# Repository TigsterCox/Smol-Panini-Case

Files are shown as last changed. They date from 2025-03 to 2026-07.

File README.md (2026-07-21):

# Smol-Panini-Case
The Smol-Panini-Case is a SlimeVR Smols Case designed to utilise integrated Filament hinge.

<p align="center">
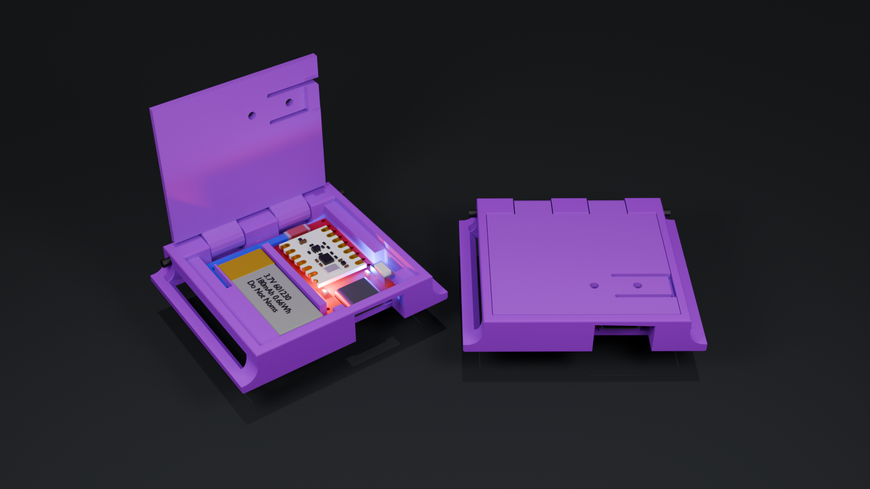
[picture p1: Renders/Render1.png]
	
</p>

# REVISION 2.1!
Revision 2.1 brings a slightly larger design in favor for strength and a better lid mechanism
 - Now locks into 90* increments
 - Lid sits flush! (no more getting it snagged!)
 - Matching insides for easy switch!

These cases have some intentionally tight tollerances on the hinges so that they are sufficiently stiff to assist with keeping the lid closed during use.
You can use a 2mm alankey or drill bit to make sure the gap is sufficient.
This case is intended to be used with 30mm straps which you can find [here](https://www.aliexpress.com/item/1005006112175102.html)

Things you will need:

 - Stacked Slime with 601230 180mah battery and button of choice (i used 3X6X2.5 button)
 - Case.stl
 - Lid.stl
 - 40-42mm of filament (per case)
 - Allen key (optional)
 - Something hot (solding iron set to the temp you print at is perfect)
 - Some wire

I would reccomend printing these out of PLA+, PETG or better @ 0.1mm layer height (0.2 is fine but doesnt look as nice).

CHECK YOUR ORIENTATIONS BEFORE PRINTING

After printing out the cases & lids you need: 
simply put the lid and case together.
push your peice of filament though leaving 1-2mm on each end, cut off the extra. (use a small allen key to help line it up if you are struggling)
Next, Using your "something hot" melt and flatten the ends of the extra filament, fusing it to the case
now give it a couple flippy flops opening and closing it.
This will just help loosen it up abit, dont worry about it getting loose too much, if you're opening it often, you're doing something wrong.

If you need some help, feel free to ping me in the #Smol-Slime Channel! @tigsteruk

Thanks go out to: 
 - Emil (Ketzal) for the name idea
 - Meia (KOUNOLAB's #1 employee) for the IMU's
 - Lexie (aka scwanf) for all of the hardwork developing smols and tollerating my harrasment
 - Shine Bright for creating the smol docs and allowing me to RTFM my way through some of this project
 - Lyall (Stacked Slime) for creating this format and providing firmware versions for use
 - The rest of the #Smol-Slime channel for all of the help with understanding how it all works

Hyperion Approved! <3

> Strap notes for your consideration; I'm a rarther heavy set 5'6 dude, I use these lengths from the strap link above:
> - Chest, Waist, Hips: 100CM 3x
> - Thighs: 60cm 2x
> - Ankles and forearms: 30cm 4x
> - Upper Arms: 40cm 2x

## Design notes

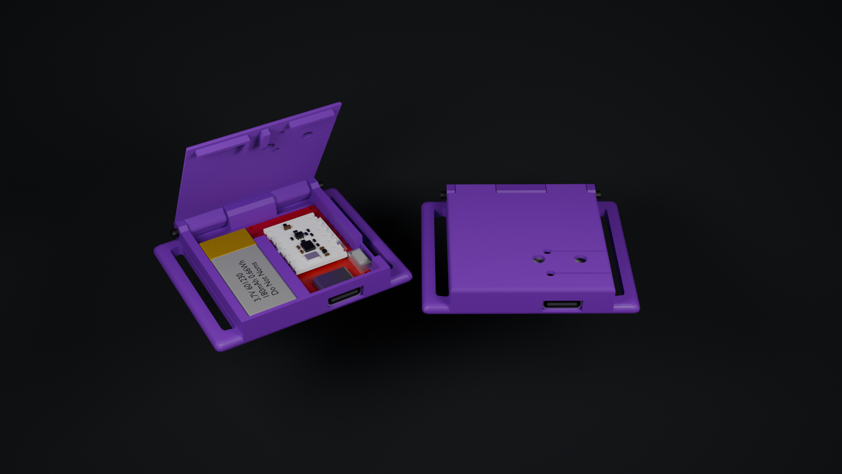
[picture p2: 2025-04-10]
Renders/RenderV1out.png

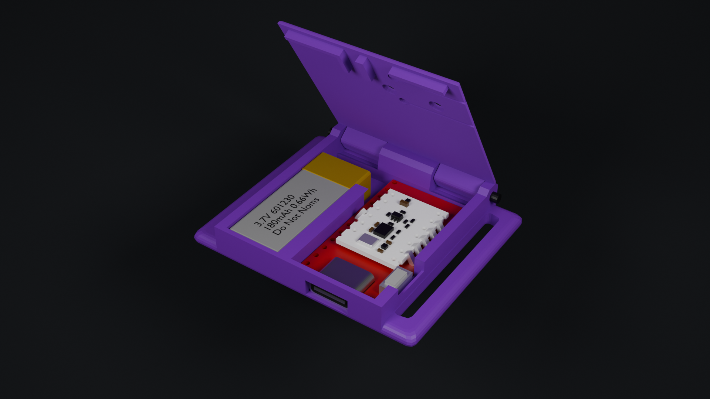
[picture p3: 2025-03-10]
Renders/RenderV1 original.png

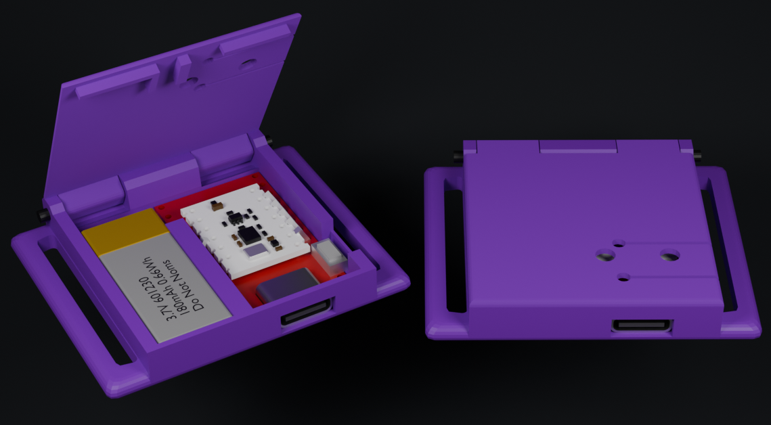
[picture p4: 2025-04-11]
Renders/Render V1crop.png

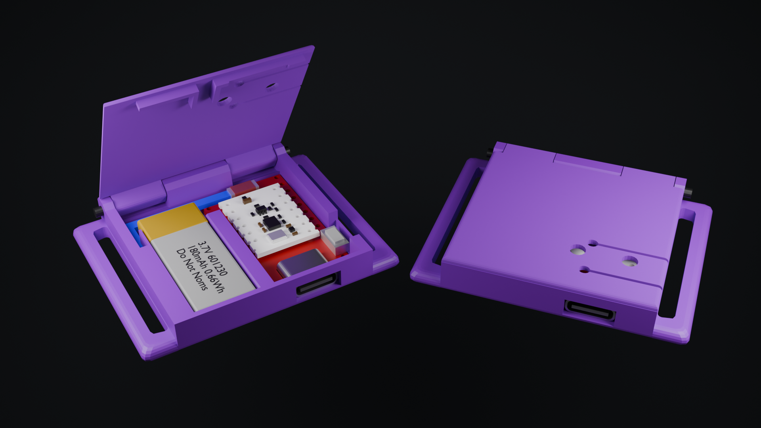
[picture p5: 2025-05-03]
Renders/Render V1.png

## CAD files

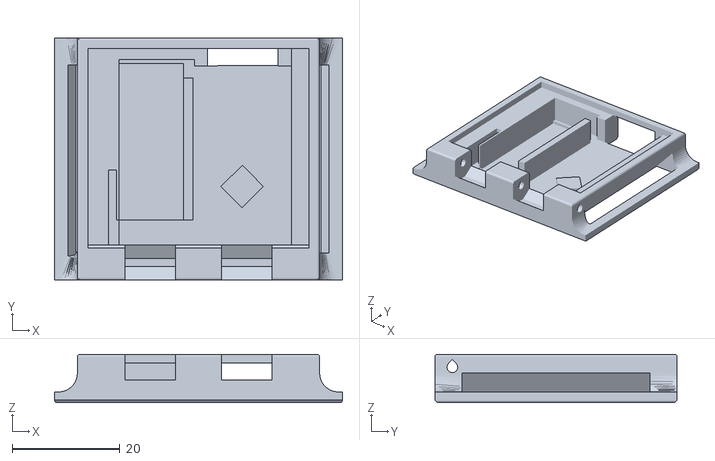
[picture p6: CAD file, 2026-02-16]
CAD/Smol Panini Case V2.stl
53.5 x 45.0 x 9.00

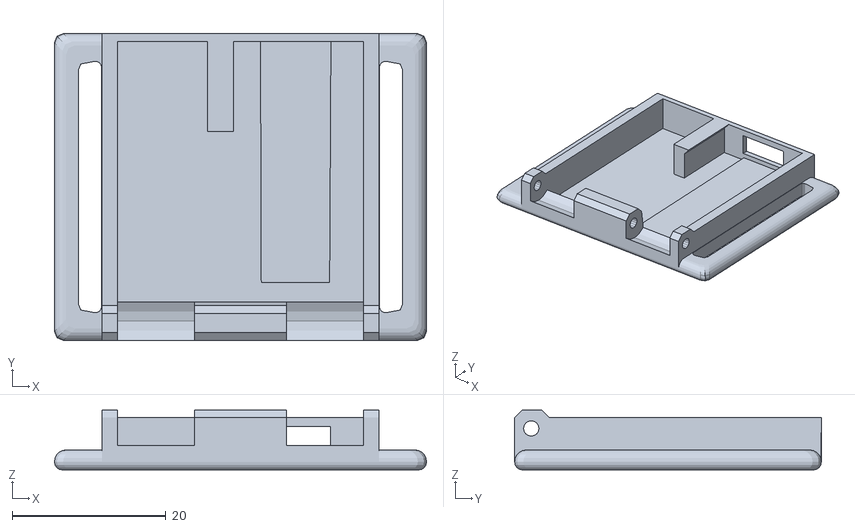
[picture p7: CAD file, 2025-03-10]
STLs/Beaver Track Case/Case.stl
48.4 x 39.9 x 7.79

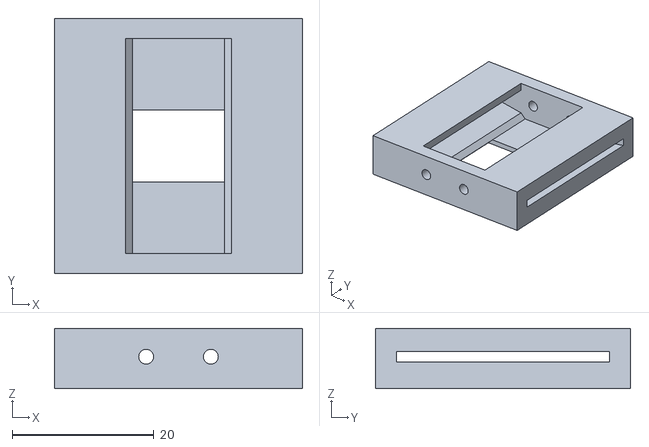
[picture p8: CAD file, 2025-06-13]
STLs/Smol Panini Case/30mm clips/Clasp.stl
35.0 x 36.0 x 8.50

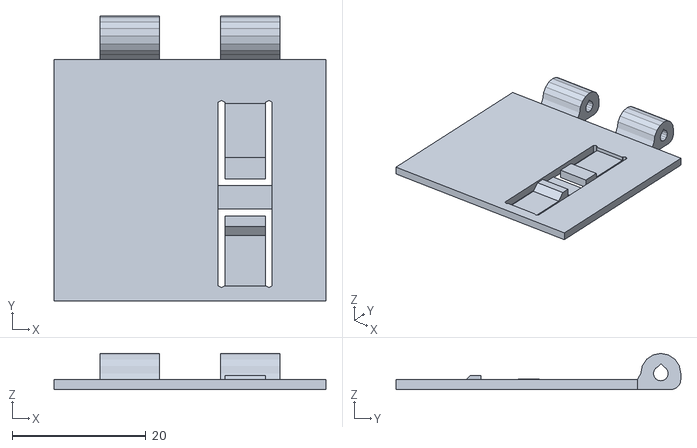
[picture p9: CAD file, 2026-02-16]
STLs/Smol Panini Case/Alternative Files/Experimental Chrysalis Lid.stl
40.7 x 42.6 x 5.41

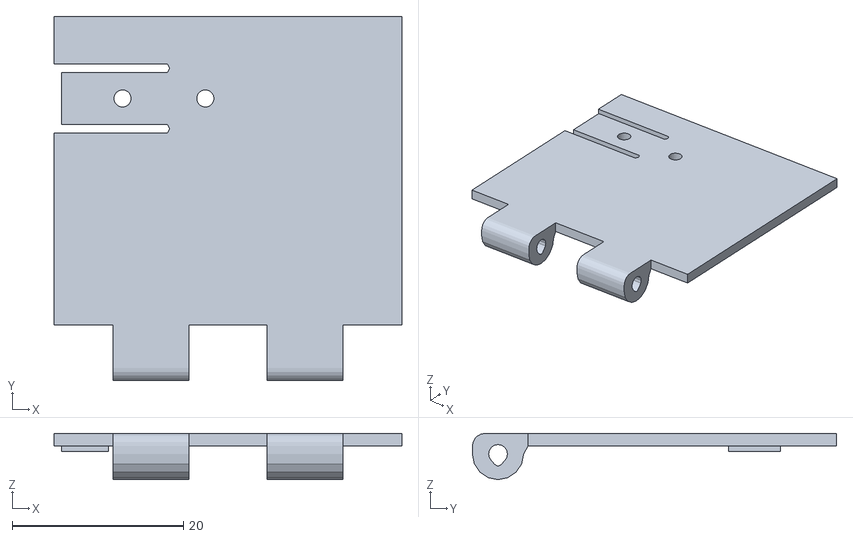
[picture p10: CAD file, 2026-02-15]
STLs/Smol Panini Case/Smol Panini Lid V3.2.stl
40.7 x 42.6 x 5.41

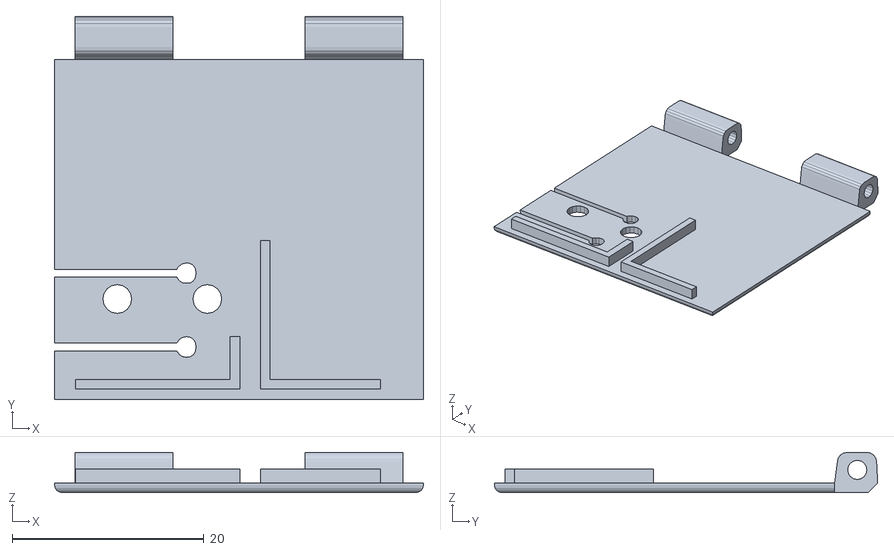
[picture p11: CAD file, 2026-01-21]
CAD/Smol Panini Lid V2.stl
38.5 x 40.0 x 4.20

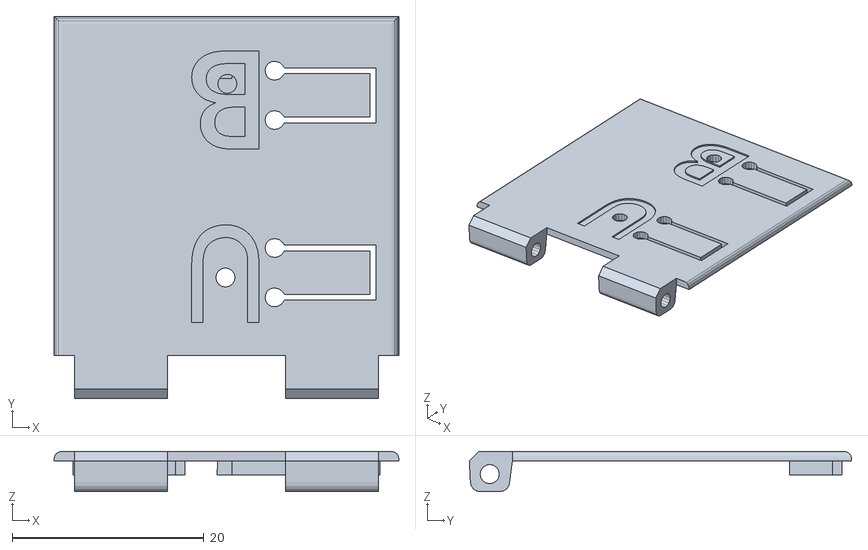
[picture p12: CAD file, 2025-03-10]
STLs/Beaver Track Case/Lid.stl
36.0 x 39.9 x 4.20

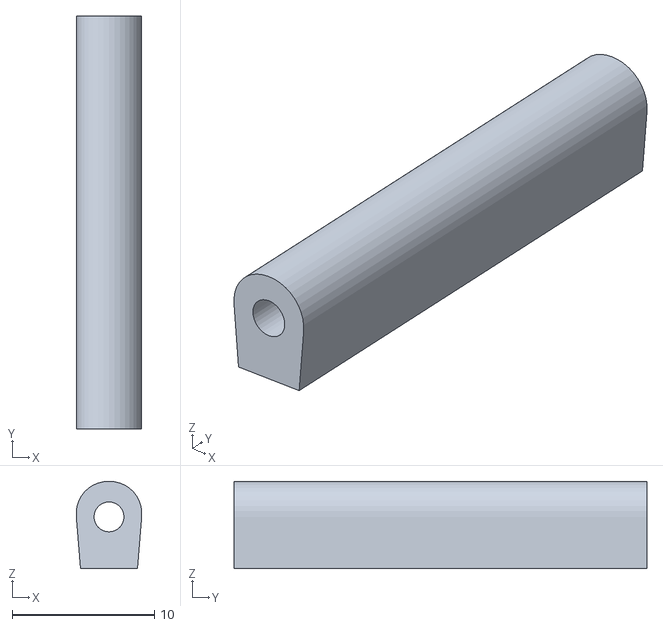
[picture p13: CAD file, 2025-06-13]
STLs/Smol Panini Case/30mm clips/Wedge x2.stl
4.60 x 29.0 x 6.14

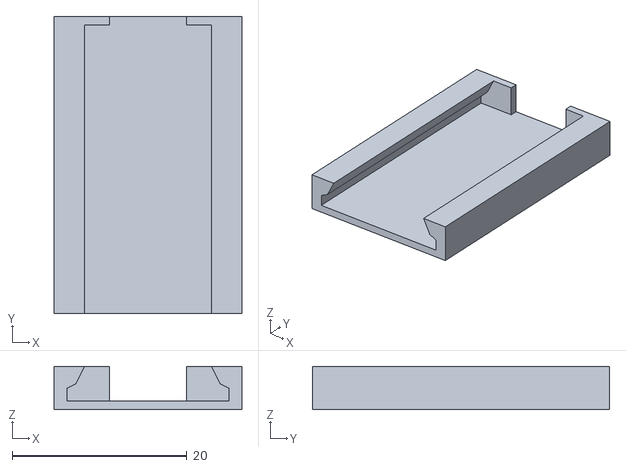
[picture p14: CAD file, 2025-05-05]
STLs/Smol Panini Case/Receiver case V0.stl
21.5 x 34.0 x 4.95

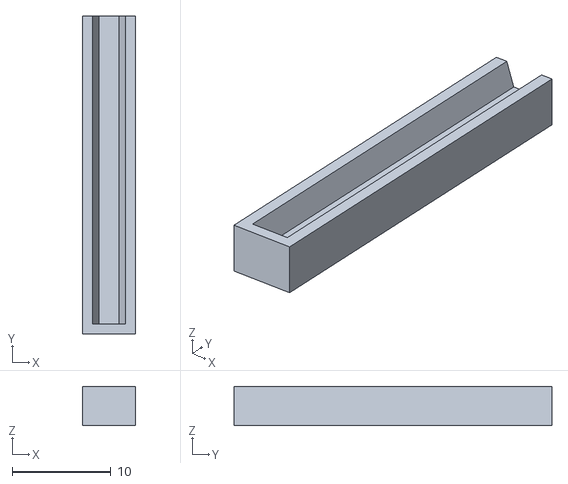
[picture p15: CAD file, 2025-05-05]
STLs/Smol Panini Case/Antenna Helper.stl
5.33 x 32.2 x 4.00

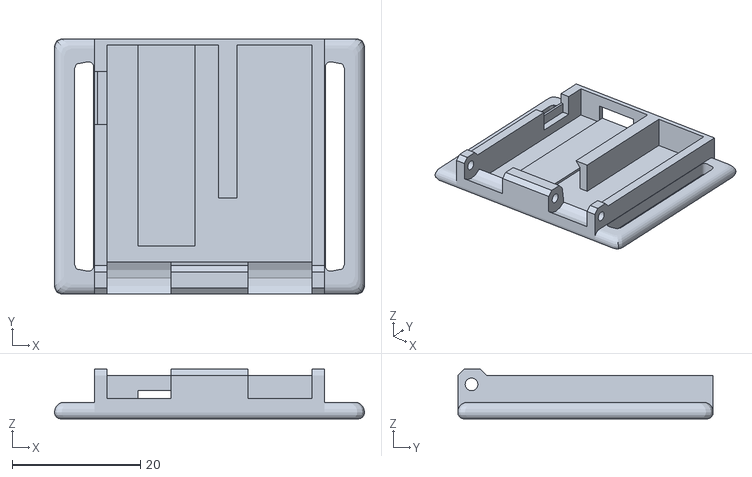
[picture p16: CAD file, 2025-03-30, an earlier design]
STLs/Smol Panini Case/V1/Case V1.stl
48.4 x 39.9 x 7.79

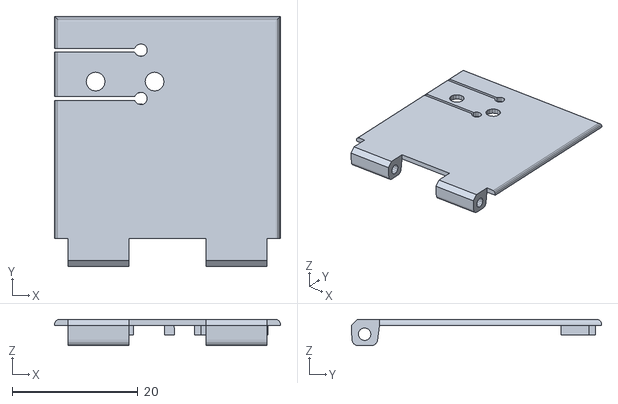
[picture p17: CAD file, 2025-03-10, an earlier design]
STLs/Smol Panini Case/V1/Lid V1.stl
36.0 x 39.9 x 4.20

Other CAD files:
STLs/Smol Panini Case/V2/Smol Lid V2.2.stl
STLs/Smol Panini Case/Alternative Files/Experimental Chrysalis Case.stl
STLs/Smol Panini Case/Smol Panini Case V3.2.stl
STLs/Smol Panini Case/V2/Smol Case V2.2.stl
CAD/Panini Slime v2.f3d

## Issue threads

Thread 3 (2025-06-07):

Separate tracker from strap mounting and use a carrier for the straps, with a catch mechanism of some sort to allow easier charging of the trackers

TigsterCox, 2025-06-07:

TigsterCox, 2025-06-07:
Make a tentioned clip, that when closed, clamps the elastic down, making adjustable sewing-less straps

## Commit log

2025-03-10 Update README.md
    Added Lyall to the thanks
    added Stacked slime as a build requirement
    added battery used and button used to stacked slime requirement
2025-03-10 Update README.md
    fixed some Typo's
    clarified the intended strapwidth
2025-03-10 Rename Panini Case.blend to Panini Case.blend.old
2025-03-10 Update README.md
    added print recs
    mentioned actually printing the damn things
    correctly my wonky spelling of allen key again
    reformatted the tip for lining up the case and lid
2025-03-10 Rekajiggered it
    Added Beaver tracker cases
    re-located Main cases
    [Case.stl, Lid.stl]
2025-03-10 Added Beavertrack CAD
    added the CAD for beaver track
2025-03-10 Read Desc
    Changed file names
    Updated Cad
    [Case.stl, Lid.stl, Smol Panini Case.blend]
2025-05-03 Revisioning has begun
    [Case V1.stl, Case.stl, Lid V1.stl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]
2025-05-03 renames, relocations, and switched to v1.1
    [Antenna Helper.stl, Case V1.stl, Lid V1.stl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]
2025-05-03 updates to cad
2025-05-03 this was never here
    [Smol Case V1.1.stl]
2025-05-03 im kinda silly 👍
    [Smol Case V1.1.stl, Smol Lid V1.1.stl]
2025-05-03 adjusted tollerances
    [Smol Case V1.1.stl, Smol Lid V1.1.stl]
2025-05-03 created receiver case and updated CAD files
    [Receiver cass V0.stl]
2025-05-03 updated photoshoot cad and updated renders
2025-05-04 updates and i cannot spell
    [Receiver case V0.stl, Receiver cass V0.stl, Smol Case V1.1.stl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]
2025-05-04 more tests and updates
    [Receiver case V0.stl, Smol Case V1.1.stl, Smol Lid V1.1.stl]
2025-05-04 updates before bed
    goodnight
2025-05-05 HOLY SHIT ACTUAL CAD LMAO
    i learned fusion all for this moment 🙏
    [Antenna Helper.stl, Panini Slime v2.f3d, Receiver case V0.stl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]
2025-05-07 updated revision number
    [Smol Case V1.1.stl, Smol Case V2.stl, Smol Lid V2.stl]
2025-06-08 added 50mm strap extention plate
    [Stendo Plate.stl, Stendo Plate_old.stl]
2025-06-10 Update Stendo Plate.stl
    [Stendo Plate.stl]
2025-06-13 uploaded V1 of strap clasp design
    [Clasp.stl, Wedge.stl]
2025-06-13 name change lol
    [Wedge x2.stl]
2025-06-13 made the clasp alil thiccer
    [Clasp.stl]
2026-01-05 Add purchase link for 30mm straps
    Updated strap size information with a link to purchase.
2026-01-05 github shenanigans
    [Antenna Helper.stl, Case V1.stl, Case.stl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]
2026-01-05 updated to include bigman strap lengths
2026-01-21 did some tidying up :)
    [Smol Case V2.2.stl, Smol Lid V2.2.stl, Smol Panini Case V2.stl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]
2026-02-15 Added alternative Chrysalis lid
    fixed some mesh issues on the case and added fillets/chamfers/whatever to make it less cutyourskin-ey
    [Smol Panini Case V3.2.stl, Smol Panini Lid V3.2.stl, Smol Panini LidV3.2 Chrysalis.stl]
2026-02-15 removed bad file
    [Smol Panini LidV3.2 Chrysalis.stl]
2026-02-15 Added Experimental Chrysalis Case&Lid
    [Experimental Chrysalis Case.stl, Experimental Chrysalis Lid.stl]
2026-02-16 modified case
    [Smol Panini Case V2.stl]
2026-02-16 fishy pushy
    made a few changes, moved battery compart over 2mm to allow more space for cable flex, removed battery compart notch, fixed lid geometry to be less strange
    [Experimental Chrysalis Case.stl, Experimental Chrysalis Lid.stl, Smol Panini Case V3.2.stl]
